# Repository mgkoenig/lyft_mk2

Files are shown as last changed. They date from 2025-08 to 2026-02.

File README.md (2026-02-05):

# LYFT mk2

This is an advanced next-level version of the famous [Lyft](https://github.com/mgkoenig/lyft) project. Apart from general improvements (lessons learned from the previous version) the focus of this re-design was placed on versatility and flexibility. Therefore, a dual-controller architecture was chosen. One controller is responsible for the desk communication only, while the second controller (__ESP32__) acts as interface platform with its enormous possibilities. Lyft can now be extended to support various access options, such as _web interfaces_ or _mobile apps_. Maybe your desk is one of the few things missing in your _home assistant_ setup? With the built-in ESP controller (running MicroPython), these and many more options are right at your fingertips.

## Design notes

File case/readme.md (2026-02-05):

Since the new design consists of two different PCBs, two different enclosures are also required: one for the ECU and the second for the HMI. All enclosure parts were created by [Extrutim](https://www.printables.com/@Extrutim), whose excellent work and attention to detail significantly contributed to the result.

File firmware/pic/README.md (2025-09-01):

The PIC controller and its firmware act as bridge module between the ESP32 and the desk. On the one hand, the controller takes care of the desk communication (including timings, move commands, error handling, etc). 
On the other hand, it provides an API which allows the ESP32 easily to access all supported features and read important information from the desk. 

## How to comunicate with the PIC controller
The controller is addressed using the UART interface with these settings: **115200@8N1**. 

## Sending a request to the controller
In order to trigger an event you need to send a certain request. Therefore, a simple communication protocol is used in order to make things easier. The structure of each request to the controller is as follows: 

[STX] [CMD] [LEN] [opt. DATA] [CHECKSUM] 

Where: 
| Element  | Description |
|---|---|
| STX | a start of transmission byte (0x4C) |
| CMD | the requested command (see API table) |
| LEN | length of optional data |
| DATA | if data is sent, it will be here |
| CHECKSUM | each request ends with a checksum byte |

## Receiving a response from the controller 
Every single request follows a response from the controller. In some cases, this response is just a simple ACK to the previous request. In other cases this response contains the requested data (e.g. current desk position, firmware version, etc). The structure of the response is as follows: 

[STX] [ECHO_CMD] [LEN] [ACK] [opt. DATA] [CHECKSUM]

As you can see, the frame has a similar structure as the request, but the content is interpreted slightly different:

| Element  | Description |
|---|---|
| STX | a start of transmission byte (0x4C) |
| ECHO_CMD | this is the same value as the received command, but it's or-ed with 0x80. For example, you requested a command code 0x12, then the echo_command will be 0x92. |
| LEN | length of optional data, but at least 0x01 due to the ACK byte |
| ACK | if there was no error, this ACK byte has the value 0x00. In case of an error, you can read an error value here (e.g. invalid command or invalid checksum). |
| DATA | the requested data (if no error occurred) |
| CHECKSUM | each response ends with a checksum byte |

..to be continued..

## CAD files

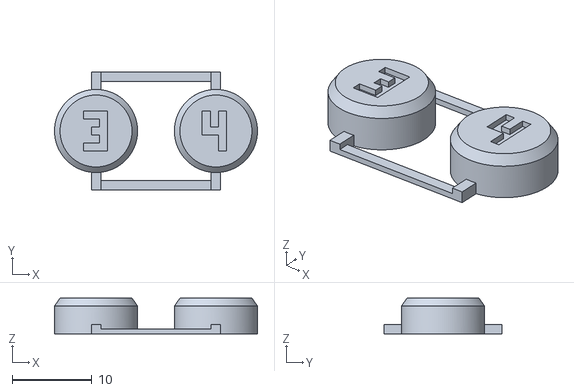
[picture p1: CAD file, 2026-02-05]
case/HMI_Button_2-3.stl
25.4 x 14.7 x 4.50

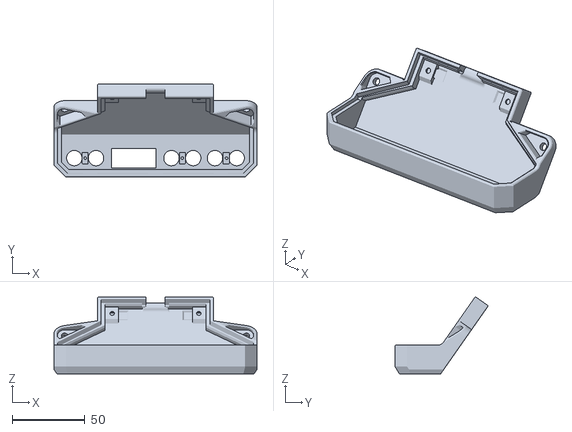
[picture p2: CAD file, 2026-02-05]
case/HMI_Case.stl
140.0 x 64.1 x 53.0

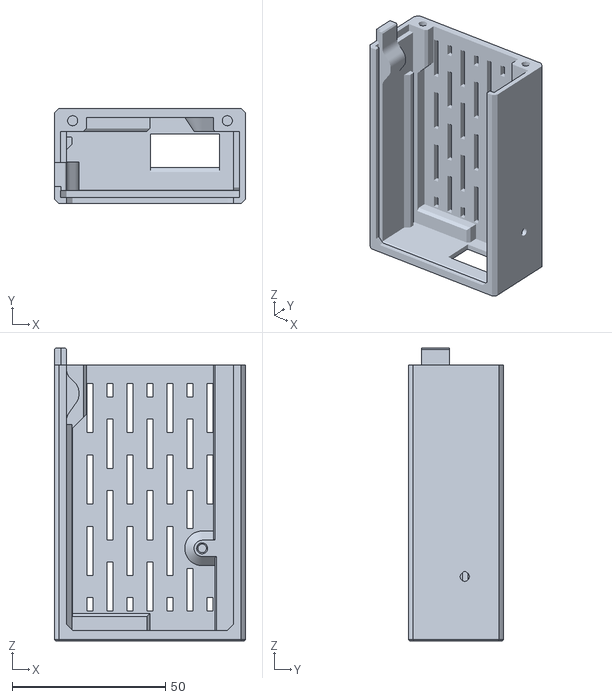
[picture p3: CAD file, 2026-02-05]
case/ECU_Case.stl
62.4 x 31.0 x 95.5

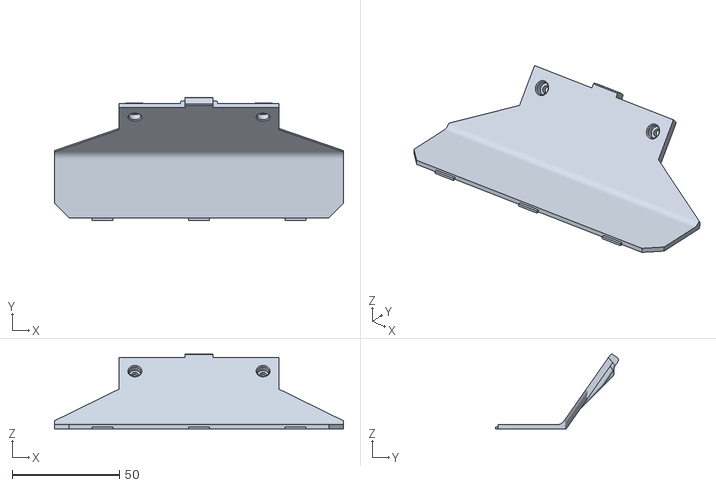
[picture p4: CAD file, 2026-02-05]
case/HMI_Lid.stl
134.8 x 57.3 x 35.0

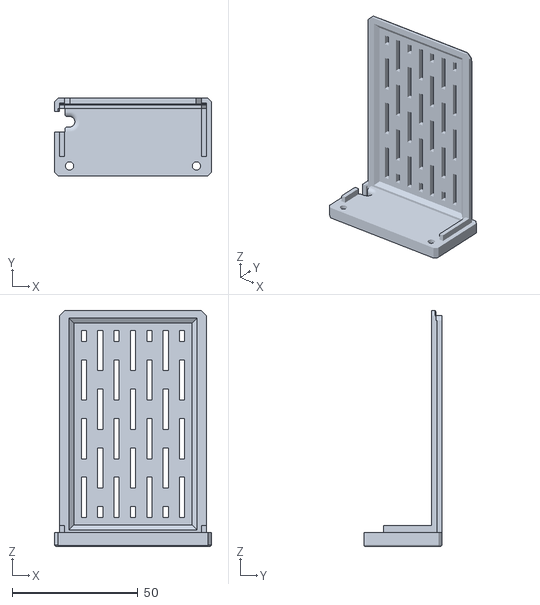
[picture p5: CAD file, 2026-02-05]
case/ECU_Lid.stl
62.4 x 31.0 x 93.7

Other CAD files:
case/HMI_Button_U-D.stl
case/HMI_Button_1-2.stl

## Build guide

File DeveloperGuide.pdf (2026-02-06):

# LYFT mk2

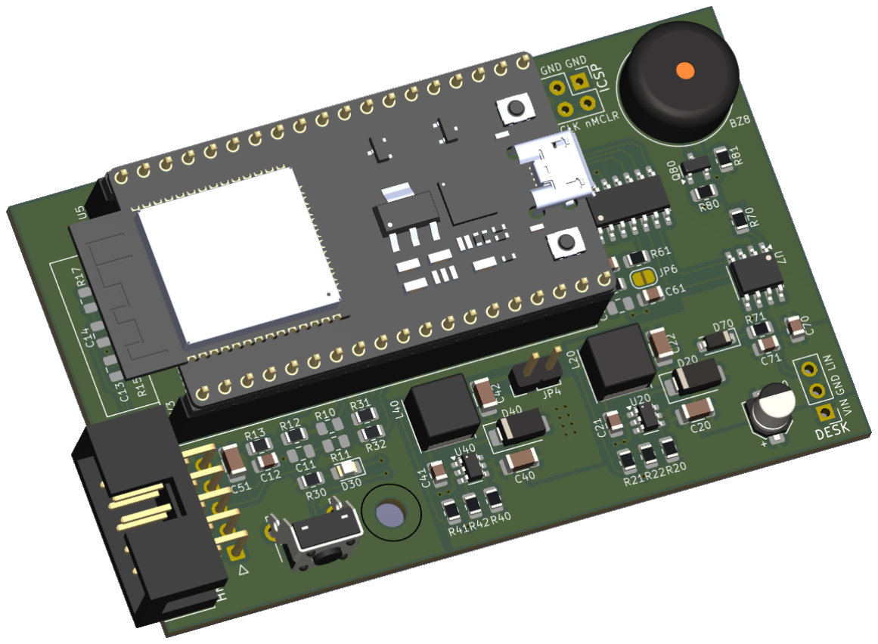
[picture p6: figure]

## Developer Guide

Welcome to LYFT mk2 !
This is an open-source DIY project designed to bring enhanced functionality and greater convenience to the famous IKEA BEKANT standing desk. The second generation of the LYFT remote control is built with both users and developers in mind: whether you want to adapt it for your own needs or contribute new features, the project is ready for you.
The redesigned dual-controller architecture allows you to control the desk using a simple Python API and run your own applications directly on the ESP platform — no detailed knowledge of the desk protocol is required, as the API and controller handle all tasks internally, enabling endless customization and innovation.
To facilitate a smooth start, the most important information has been summarized here for quick and efficient reference. All source files (hardware and software) are available on the GitHub repository, which can be accessed by scanning the QR code.

Getting Started

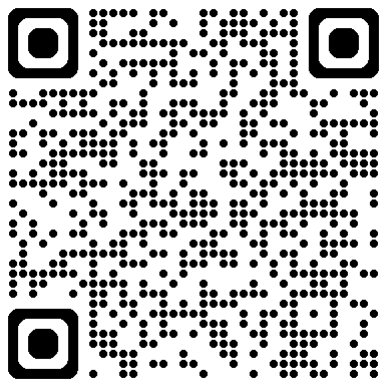
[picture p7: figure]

To upload your own software to the ESP module, connect it using a USB cable.

Warning: Before connecting the USB cable, Jumper four (JP4) must be removed. Failure to do so will damage the board!

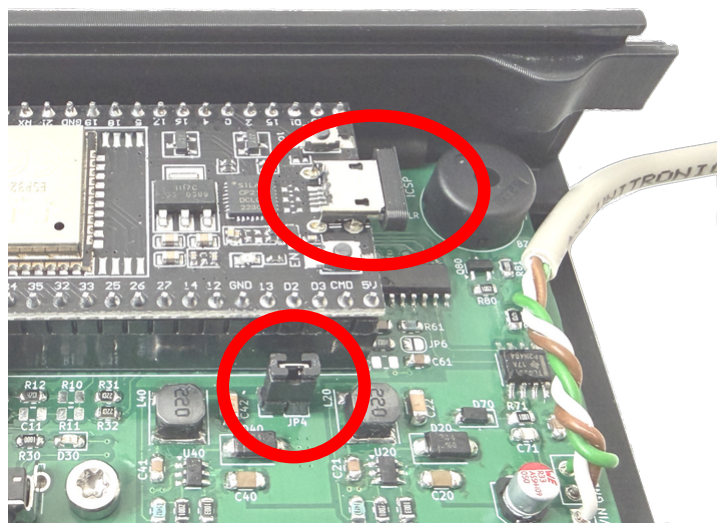
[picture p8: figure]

Jumper closed,
no USB cable connected

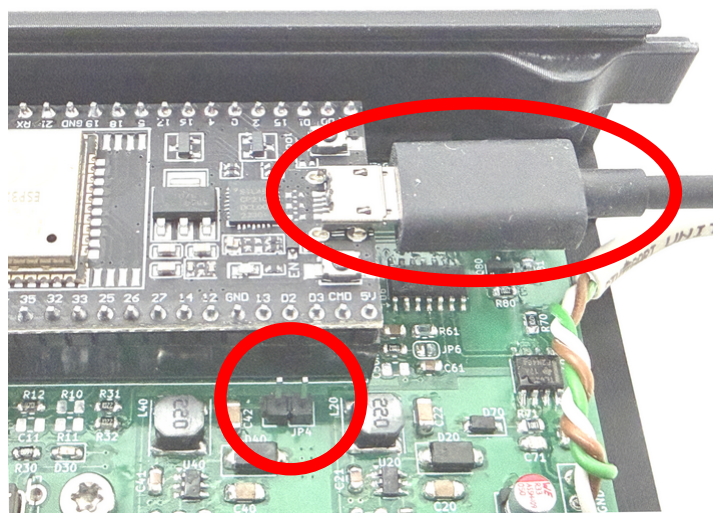
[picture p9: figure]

Jumper opened,
USB cable connected

Once the USB cable is connected to the host controller (ESP module), a connection to the PC must be established within 3 seconds. After that, no further input via the USB port will be recognized.

To communicate with the desk controller, the Bekant library must first be imported into the project. The library is already installed on the ESP module and can also be downloaded from the GitHub repository. After that, a desk object must be instantiated.

import bekant

desk = bekant.Bekant()

The desk communication must be explicitly initiated by the host controller (ESP
module) using the | startup() | command. The startup routine establishes
communication with the desk and sets the motors into operating mode. After a brief startup phase (approximately one second), the desk is ready for use. Communication can also be disabled using the shutdown() command.

desk.startup()

To move the desk, it is recommended to determine the highest and lowest motor positions first. The following queries can be used for this purpose. Every target position must lie within these two limits.

desk_upper_limit = desk.get_upper_limit() desk_lower_limit = desk.get_lower_limit()

The current desk position can be read using the | get_position() | command. The
returned value is of type int. The read position must be between upper_limit and
lower_limit.

desk_position = desk.get_position()

In order to move the desk to a desired position, the simple set_position() command can be used. The desk will automatically move to the specified position and stop once it is reached.

target_position = 2000
desk.set_position(target_position)

The desk can be stopped at any time using the stop() command.

desk.stop()

To avoid unexpected interruptions or error states, it is recommended to use the built-in watchdog of the desk controller. However, it should only be enabled after the startup routine, so that this routine can run without interruption. Once the watchdog is activated, a request must be sent to the desk controller every 100 ms. For example, the current desk position or the operating state can be queried. If no request is received, the desk controller will be reset by the watchdog. After a reset, the desk controller must be reactivated using the startup() function.

If necessary, the watchdog can be temporarily disabled using the
watchdog_disable() function.

desk.watchdog_enable()

To determine the current state of the desk, the get_state() function can be used. It returns a unique, current operating mode (e.g. idle, moving, limit reached, ...). The exact values and their corresponding states can be found in the Bekant library (class
State).

desk.get_state()

The Bekant library provides many additional functions. Further details can be found directly in the bekant.py library file or the GitHub repository. Finally, it should be noted that the existing implementation and usage of the library can serve as a good reference for how to use it effectively.

I wish you much enjoyment and success in extending and adapting the capabilities of your desk!

Happy coding!

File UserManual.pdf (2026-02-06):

# LYFT mk2

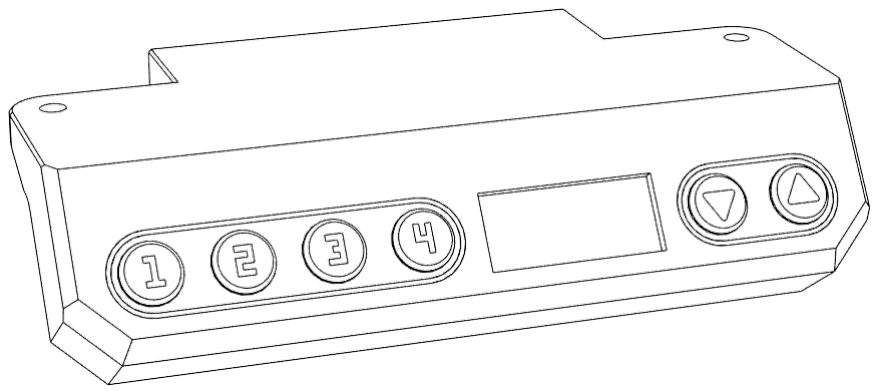
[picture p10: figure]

## User Manual

### I M P O R TA N T I N F O R M AT I O N

LYFT mk2 is a sophisticated remote control for electric height adjustable desks, compatible with the famous IKEA BEKANT desk. Designed as a plug & play solution, you can easily replace your originally provided remote control. LYFT mk2 comes completely assembled and is ready to use out of the box.

This project is an open-source DIY project and comes therefore without any liability or warranty. Usage of LYFT mk2 is always at your own risk. The originator is not liable of any damage the remote might cause. All source files are published on GitHub (github.com/mgkoenig/lyft_mk2) and licenced under the MIT license. Feel free to take a closer look at the design or to improve LYFT mk2 with even more useful features customised to your needs.

All product and company names are trademarks™ or registered® trademarks of their respective holders. Use of them does not imply any affiliation with or endorsement by them. IKEA is a registered trademark of Inter IKEA Systems BV.

Disclaimer of liability: In no event shall the originator be liable for any direct, indirect, punitive, incidental, special, consequential damages, to property or life, whatsoever arising out of or connected with the use or misuse of this product.

Exclusions from warranties: By purchasing this product you expressly agree that use of this product is at your sole risk. The originator does not and cannot warrant that the product will operate without errors.

All information and products described in this manual are provided on an “AS IS” basis. The originator does not make any representations or warranties of any kind, express or implied as to the operation of this product or the information made available to you, including implied warranties of merchantability and fitness for a particular purpose.

Furthermore, the originator's warranties for this product exclude any claims by the customer based on defects in the product caused by the customer, or by third parties beyond the originator's control.

2 | Document version 2.0 (12/2025)

### F U N C T I O N A L L AY O U T

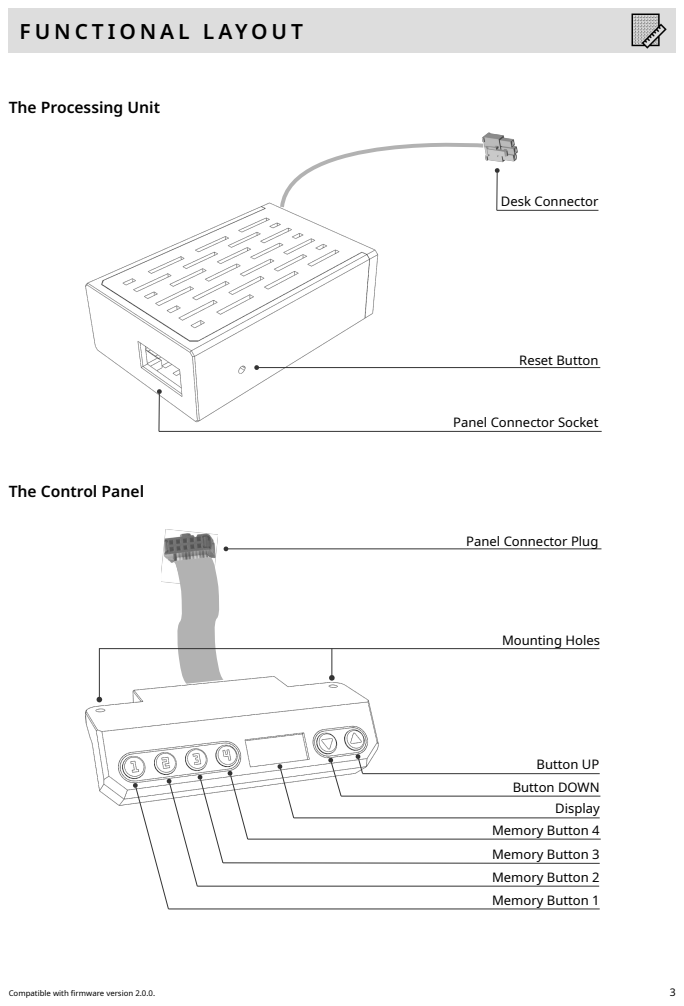
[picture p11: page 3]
Compatible with firmware version 2.0.0.; Desk Connector; Button UP Button DOWN Display Memory Button 4 Memory Button 3 Memory Button 2 Memory Button 1; Mounting Holes; Reset Button

The Processing Unit

Panel Connector Socket

The Control Panel

Panel Connector Plug

### I N S TA L L AT I O N

In order to use LYFT mk2, choose your preferred handling side and mount the control panel on the bottom edge of the desk. Use the destined mounting holes on the housing. Since no screws are provided with the shipment, you might use the original screws which were delivered together with the desk or use any two conventional [3 x 16mm] or [4 x 5/8”] wood screws instead. The processing unit can be stored in the mesh tray under the tabletop.

It’s absolutely necessary to connect all devices in the correct order. First, the control panel must be connected with the processing unit. After that, the processing unit can be connected to the desk.

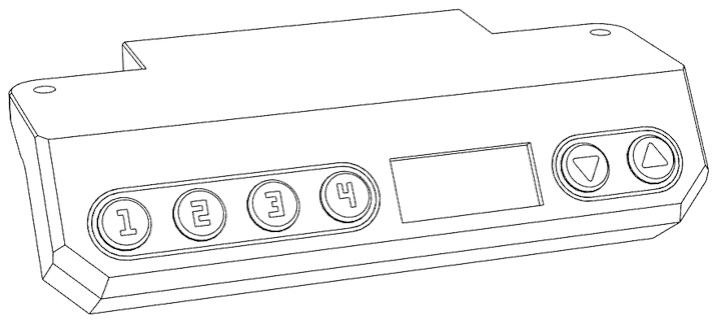
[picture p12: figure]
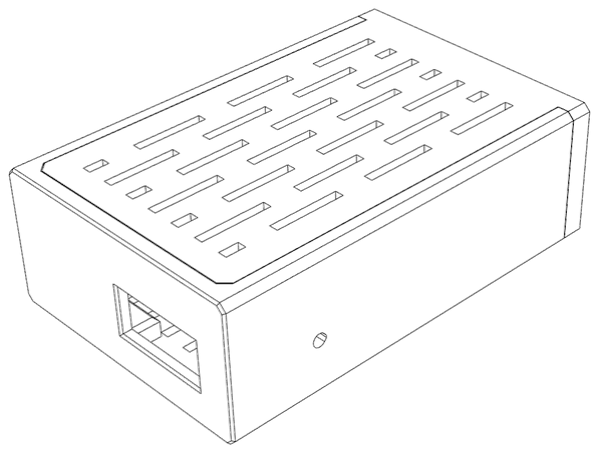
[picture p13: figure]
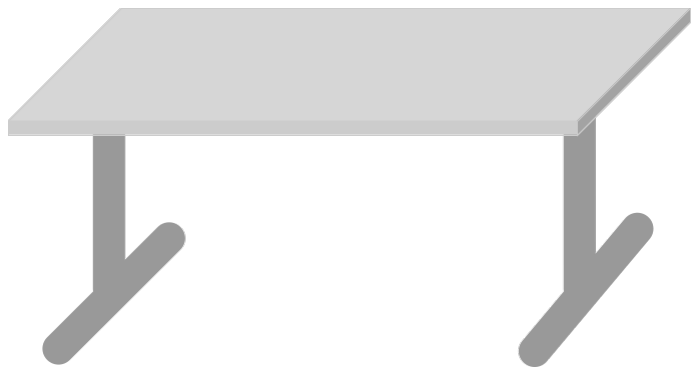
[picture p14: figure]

It takes about 5 seconds for the remote control to be ready for use after being plugged in.

1

2

### B A S I C F E AT U R E S

M O V I N G U P
To move your desk upwards, just press and hold the UP button on your LYFT remote control. The motors will automatically stop as soon as you release the button or the upper limit of the height is reached.

M O V I N G D O W N
To move your desk downwards, just press and hold the DOWN button on your LYFT remote control. The motors will automatically stop as soon as you release the button or the lower limit of the height is reached.

M O V I N G T O A S A V E D P O S I T I O N
If you have previously saved a comfortable desk position to one of the memory buttons (see the description in the upcoming settings chapter), you can move the desk to this height by pressing the corresponding button.
Compatible with firmware version 2.0.0. | 5

### S E T T I N G S M E N U

E N T E R T H E S E T T I N G S M E N U
In order to make any changes of the settings or to save a current desk position, you need to enter the settings menu. The menu is accessed by pressing the UP and DOWN buttons simultaneously for at least 2 seconds.

N A V I G A T E T H E S E T T I N G S M E N U
You can walk through the settings menu by using the UP and DOWN buttons to scroll to the next or previous page respectively.

L E A V E T H E S E T T I N G S M E N U
To exit the settings menu nothing special has to be done. Six seconds after the last button was pressed, the menu will save all its current settings and return to its default screen, showing the desk height.

S A V E A P O S I T I O N [ P ]
To save the current desk position, just enter the settings menu. The first entry of the menu shows a [P] which stands for position. By pushing one of the four memory buttons you will save the current height to the selected button.

2 sec.

D I S P L A Y B R I G H T N E S S [ L ]
You can change the brightness of the display to four different levels. Navigate within the settings menu to page [L]. Then, select the intensity by pushing one of the four memory buttons. Each button sets the brightness to a pre-defined value.

A U D I O C O N T R O L [ A ]
LYFT mk2 is equipped with a built-in audio transducer to generate audio signals and alarms. Navigate to menu page [A] to enable or disable these alarms.

D I S P L A Y - O N T I M E [ F ]
After pushing a button or adjusting the desk height to your preferred position, the display will stay on for a couple of seconds. You can change the display-on time on menu page [F]. Choose between 5, 10, 15, or 20 seconds display-on time using the memory buttons.

M E A S U R E M E N T U N I T [ U ]
By default the height of the desk is shown in centimetres. However, you can change the displayed unit to inch. Go to the unit page [U] within the menu and select your preferred measurement unit using memory button 1 or 2.
Compatible with firmware version 2.0.0. | 7

L E V E L C O R R E C T I O N [ C ]
The shown desk height might not be accurate due to level adjustment screws or a thicker tabletop. Therefore, you have the opportunity to tune the displayed position. Go to the level correction page [C] and set an offset value to the current height. The offset range is between plus/minus 9 centimetres. The offset value is always set as centimetre value – no matter which measurement unit you have selected. Use memory buttons 1 or 2 to increase or decrease the value.

### T R O U B L E S H O O T I N G

In rare cases, it might happen that the motors don’t respond to entries of the LYFT mk2 remote. In such a case, please disconnect your IKEA BEKANT desk from the power outlet for five minutes (it takes that long to discharge all remaining power) and try again. You can still double-check the flawless operation of your desk using the original remote control.

### A C K N O W L E D G M E N T S

All icons by icons8.com.

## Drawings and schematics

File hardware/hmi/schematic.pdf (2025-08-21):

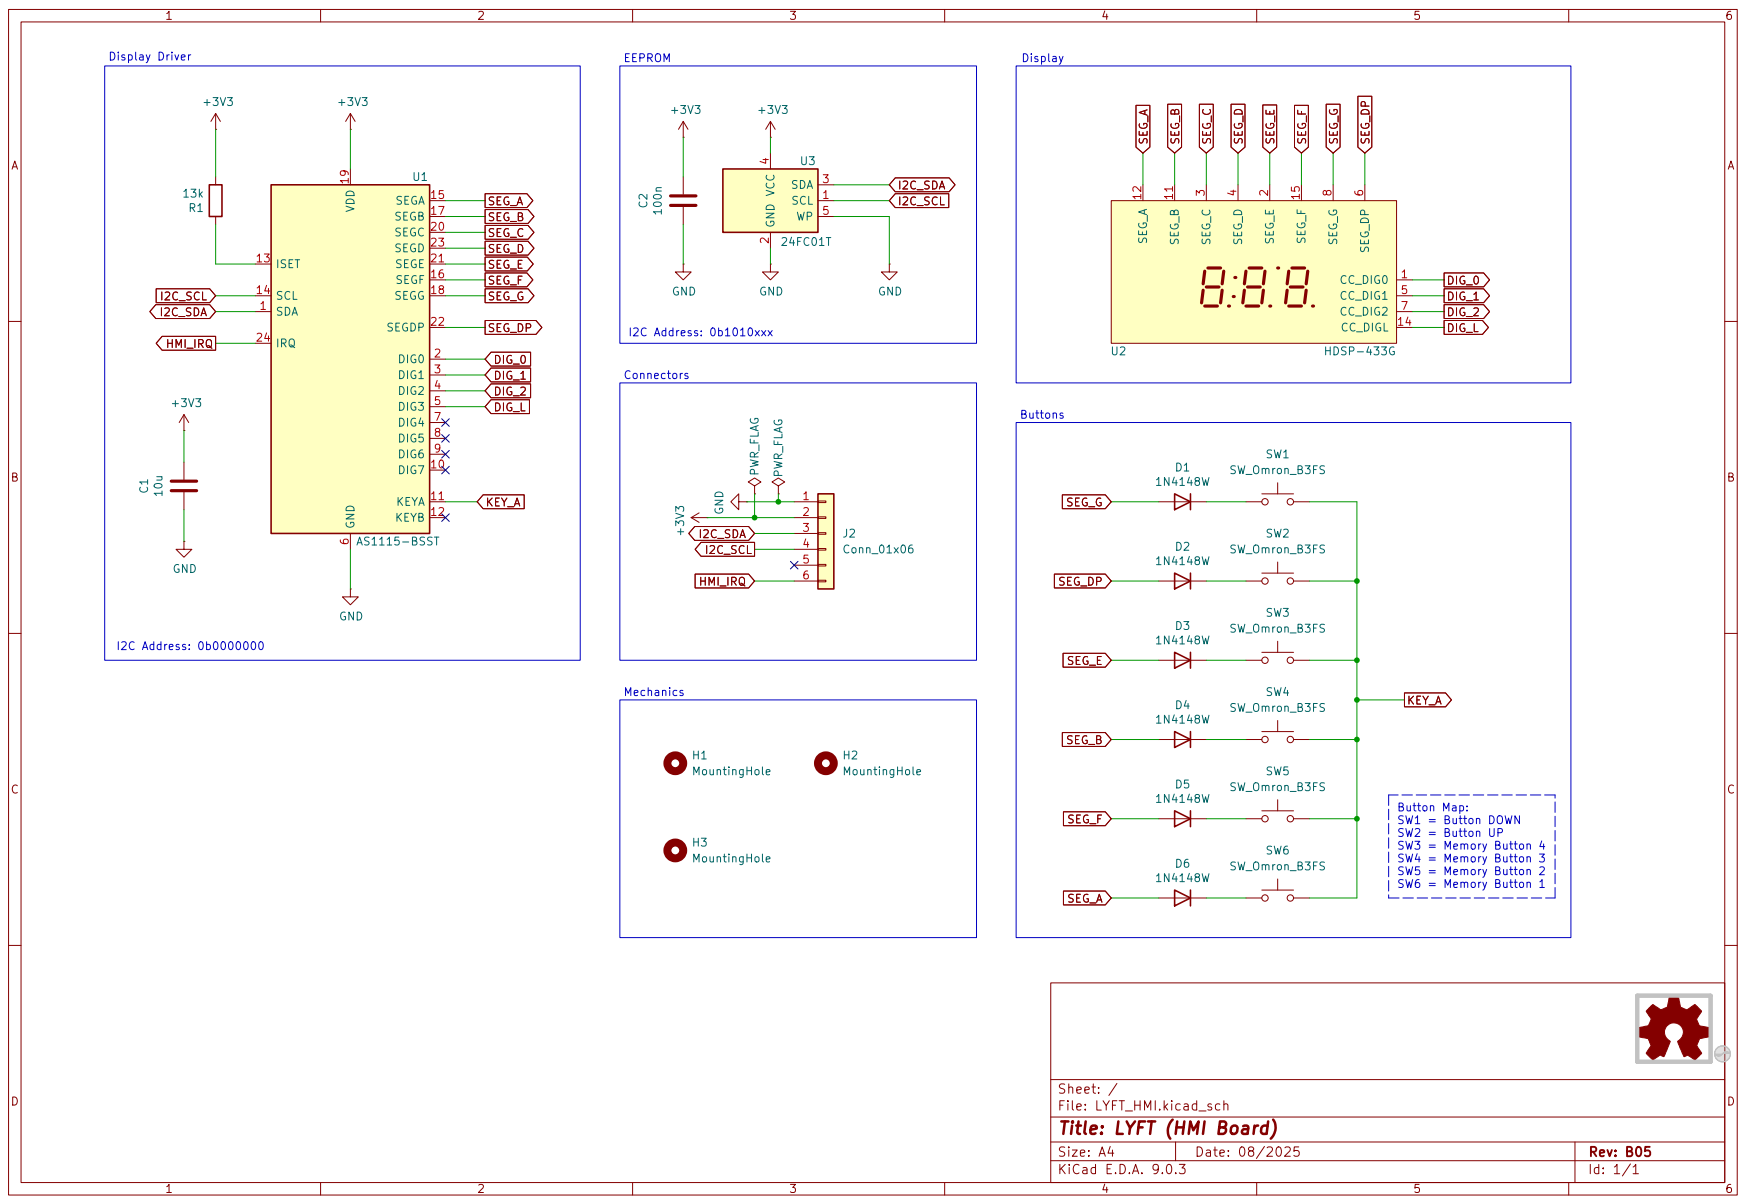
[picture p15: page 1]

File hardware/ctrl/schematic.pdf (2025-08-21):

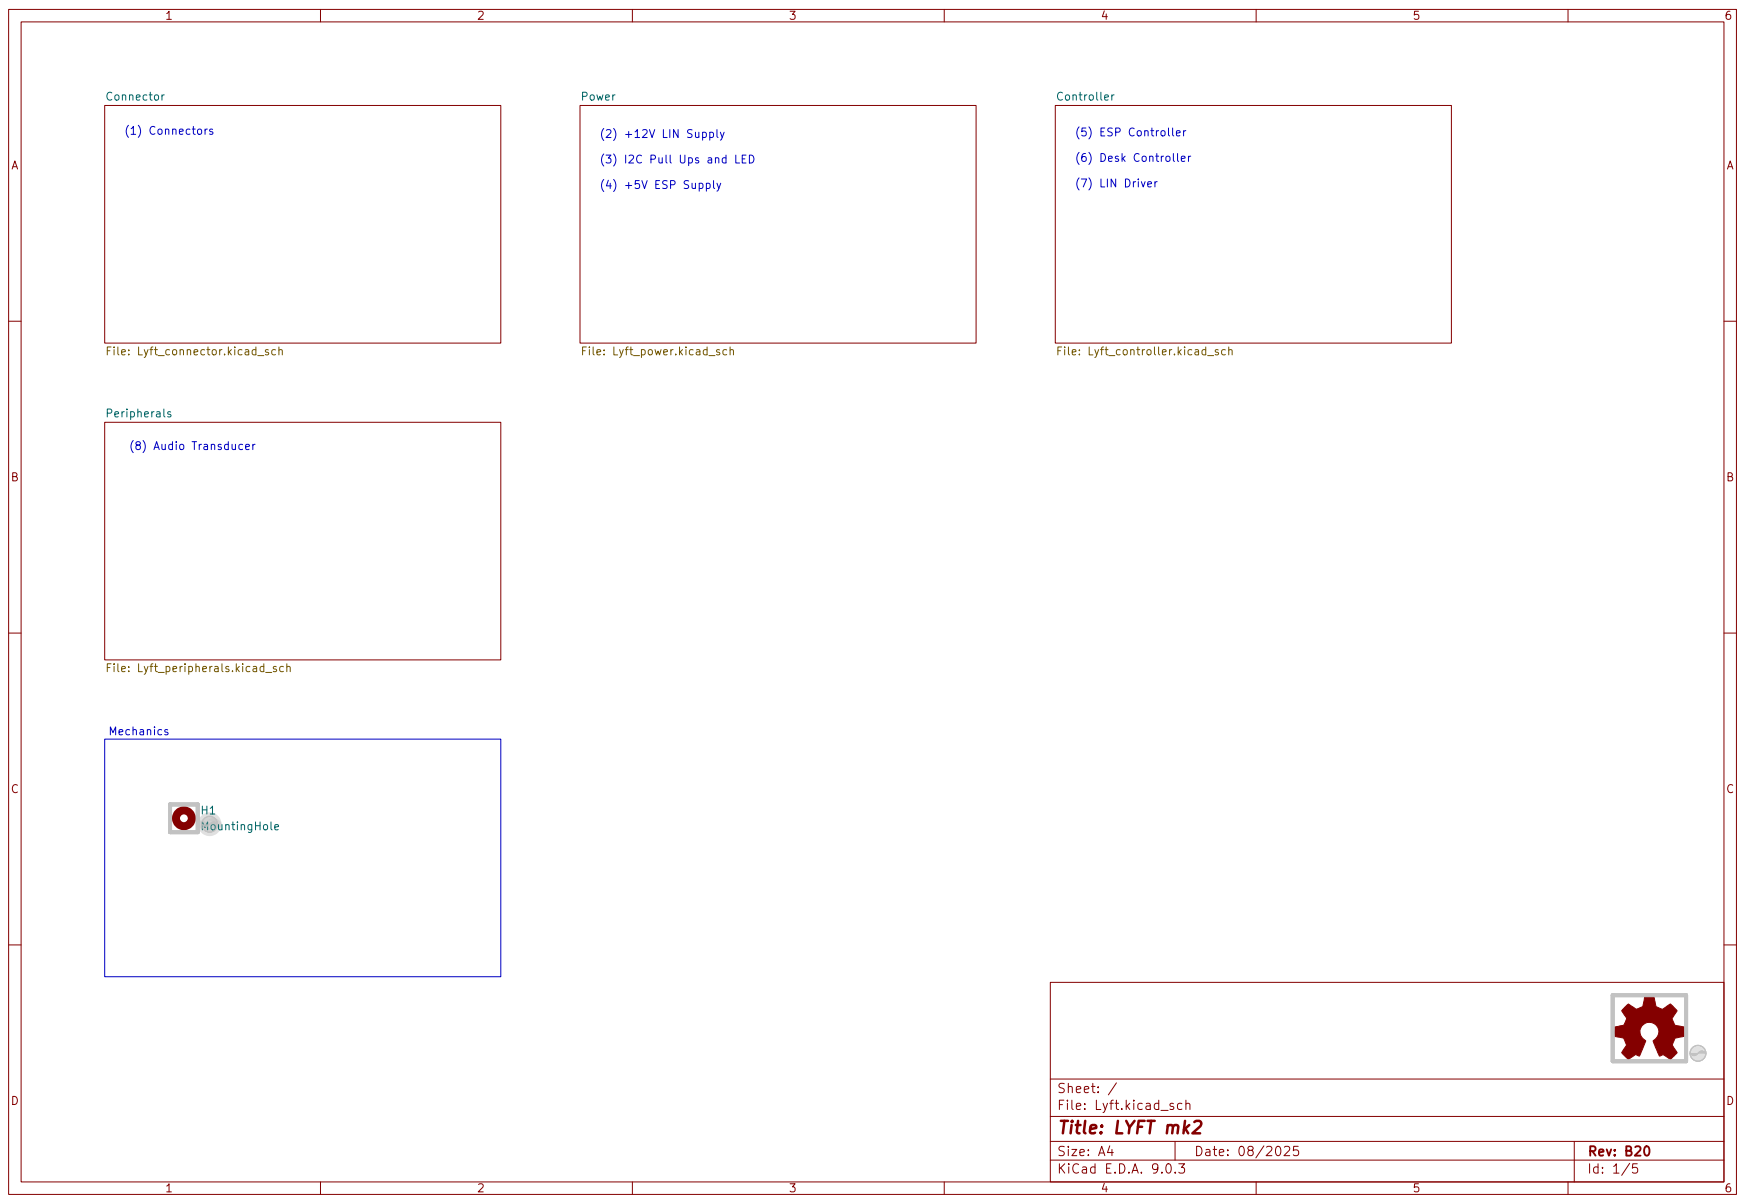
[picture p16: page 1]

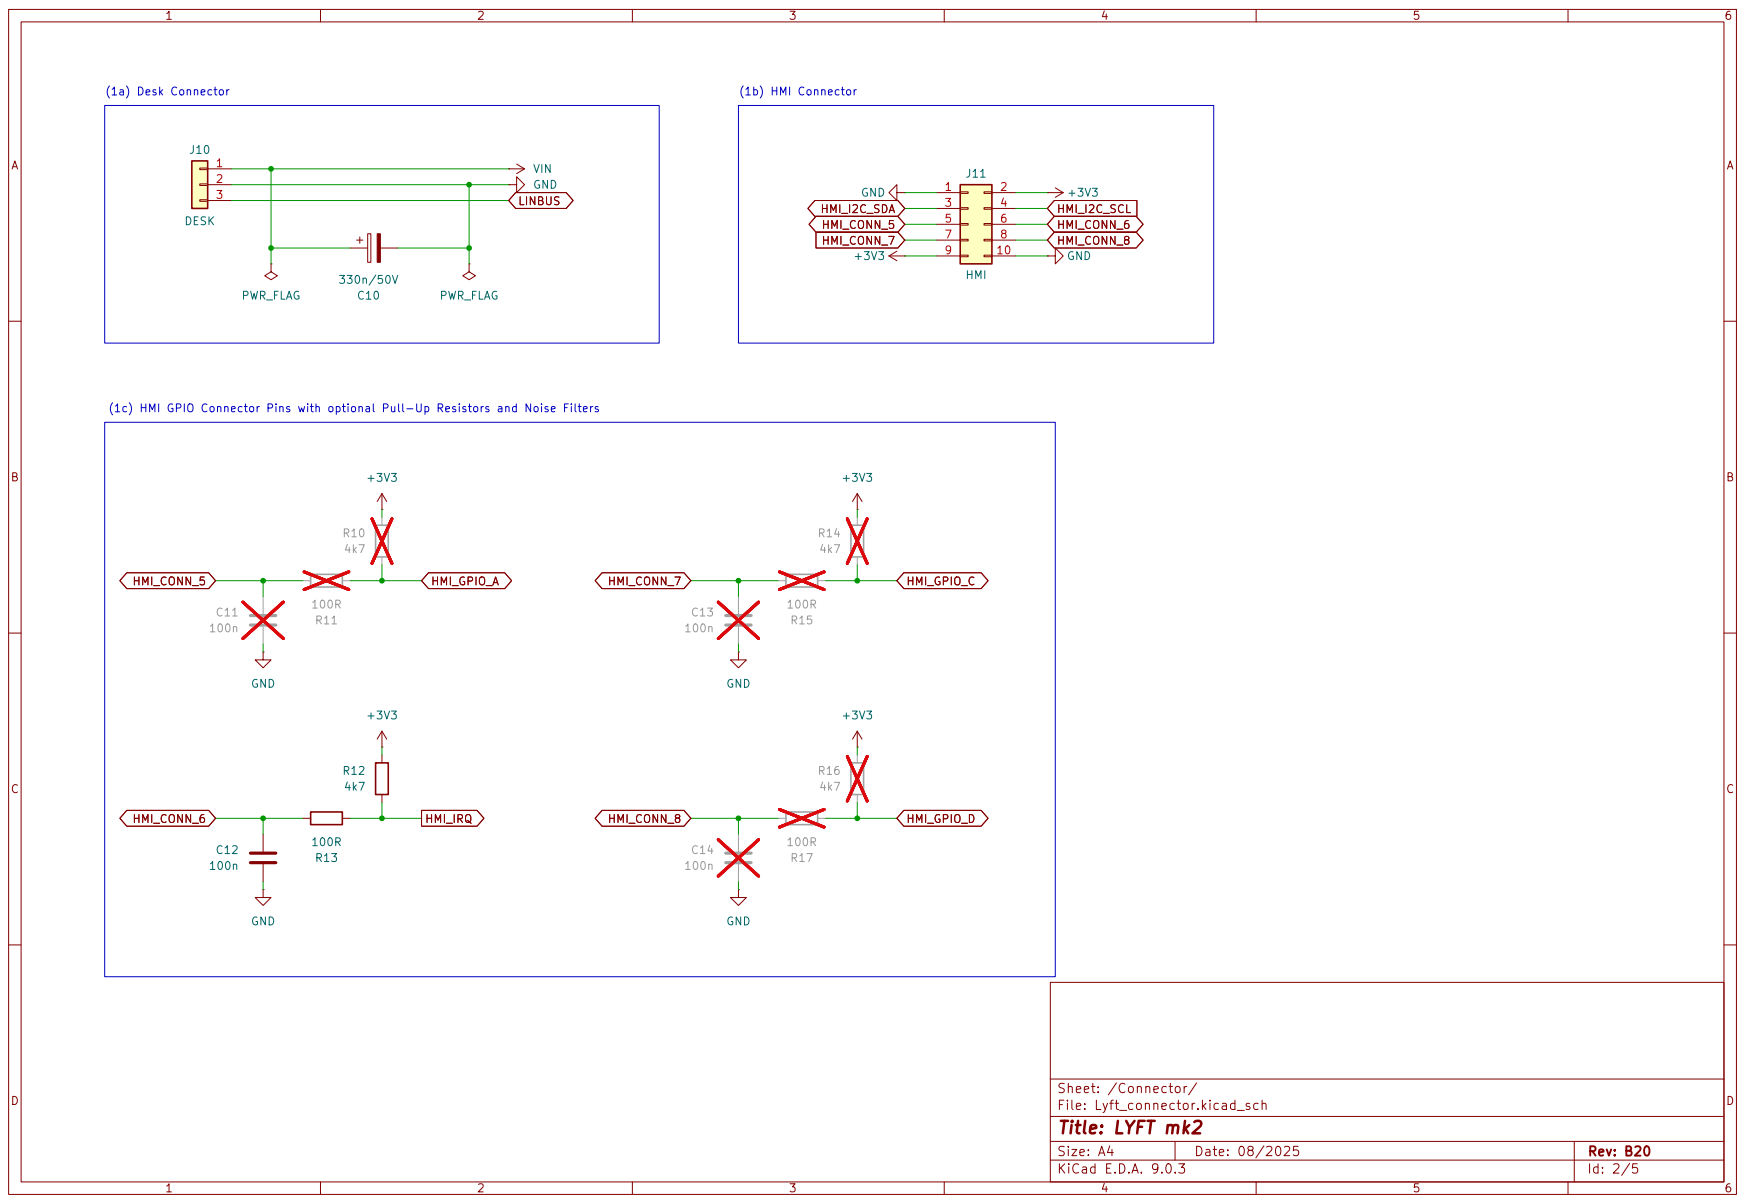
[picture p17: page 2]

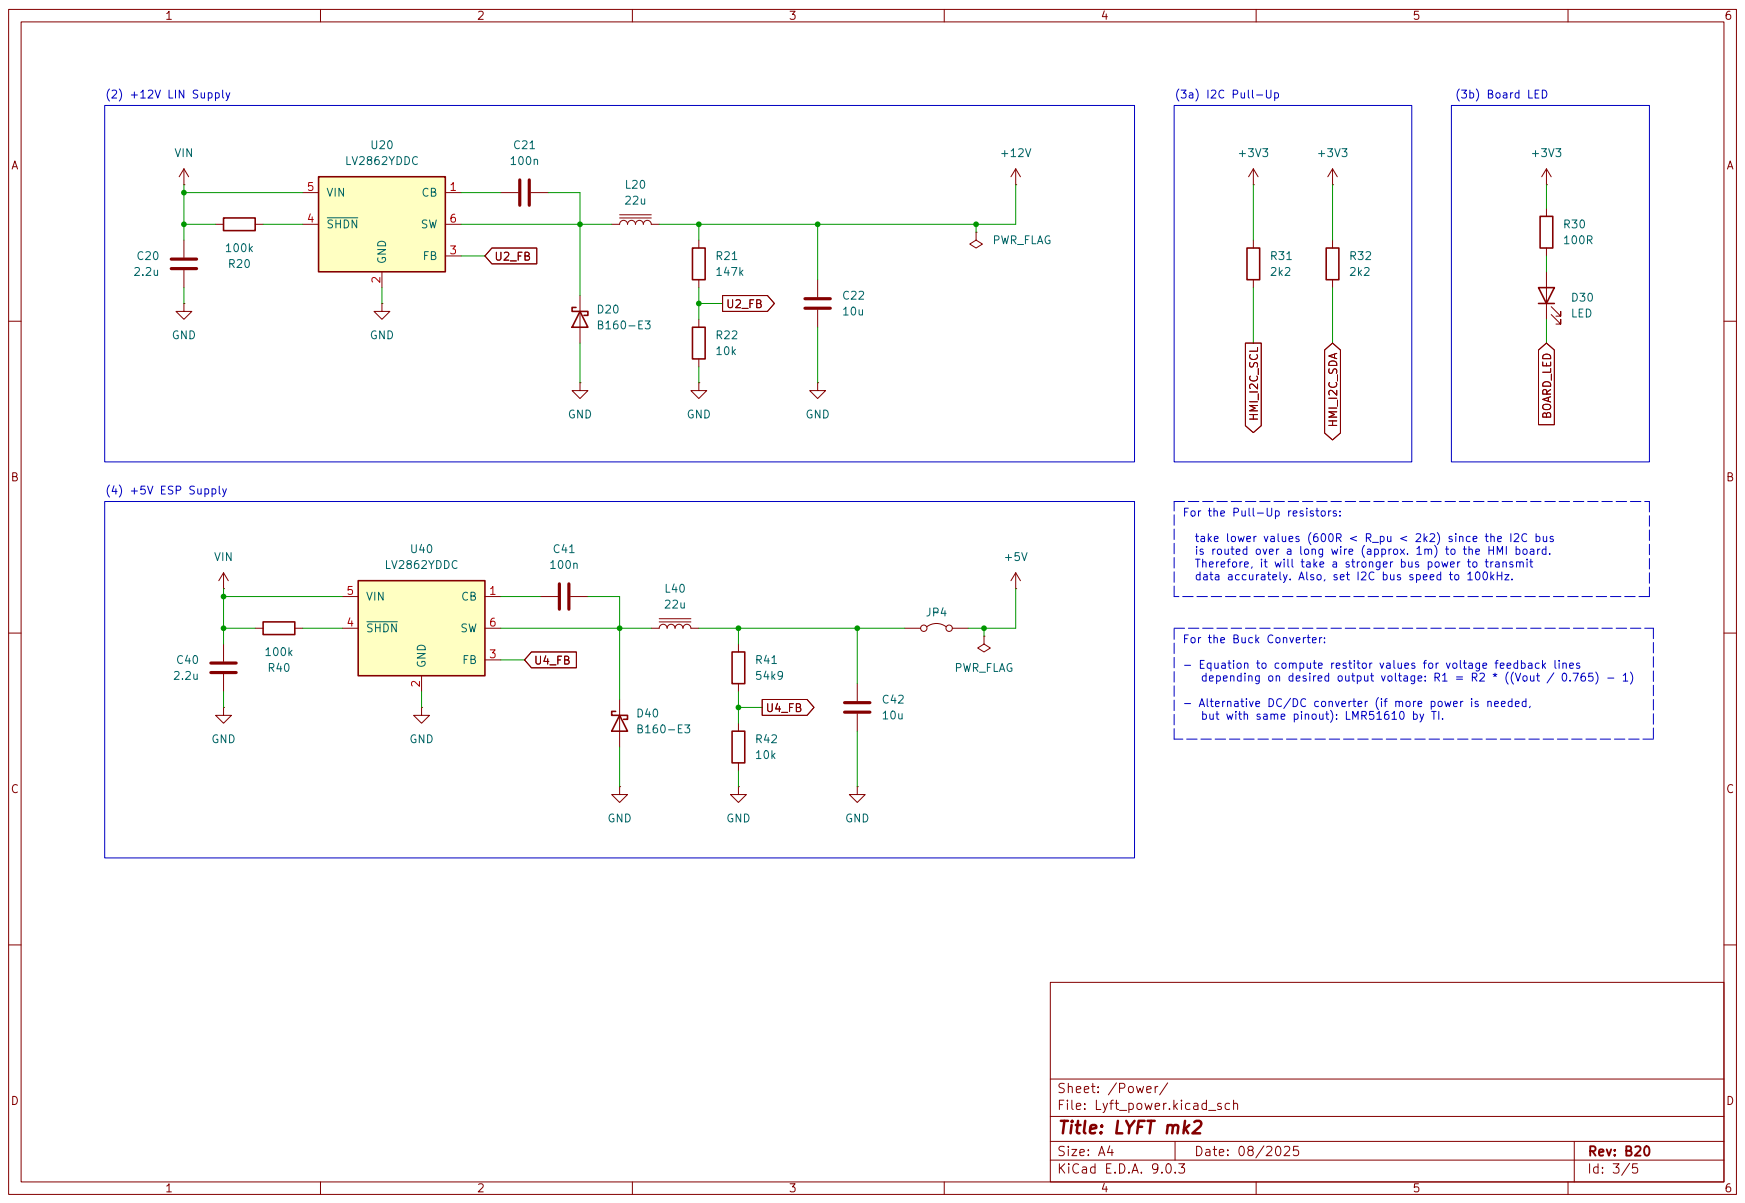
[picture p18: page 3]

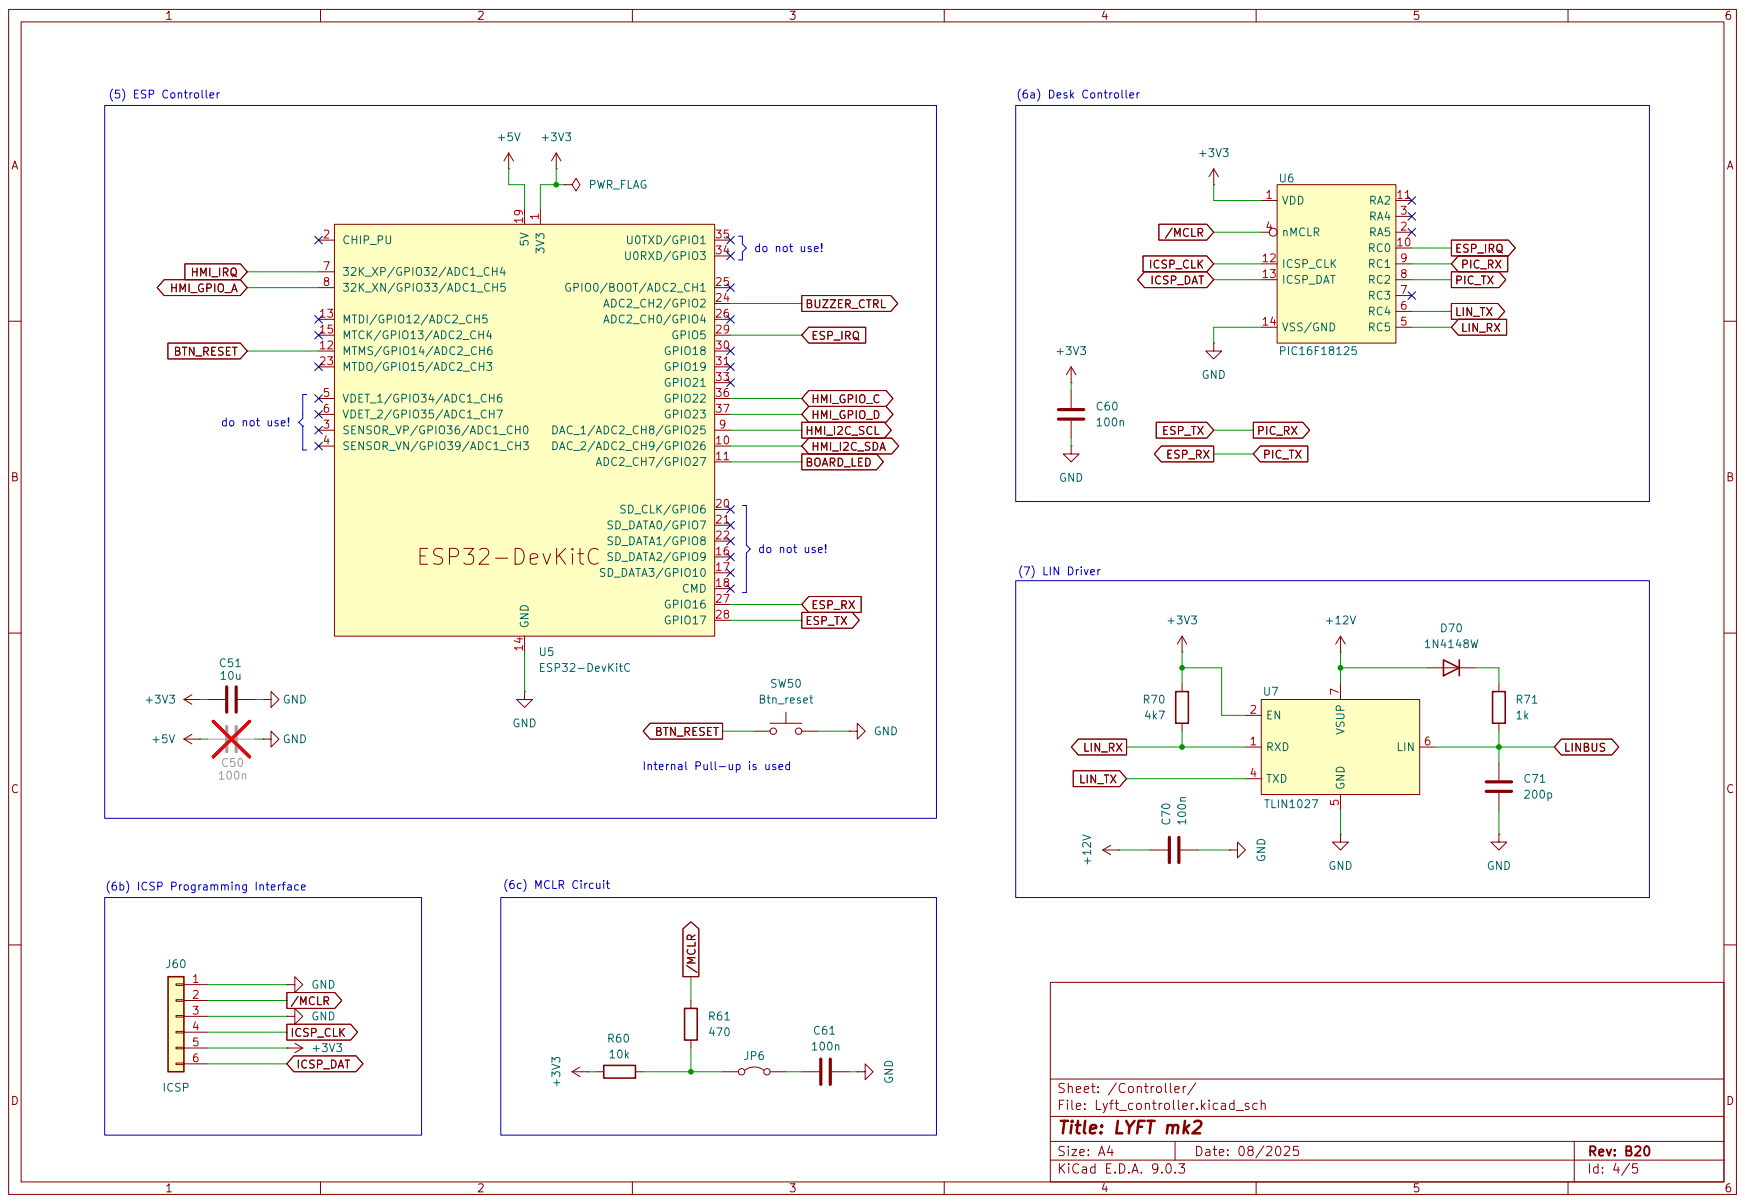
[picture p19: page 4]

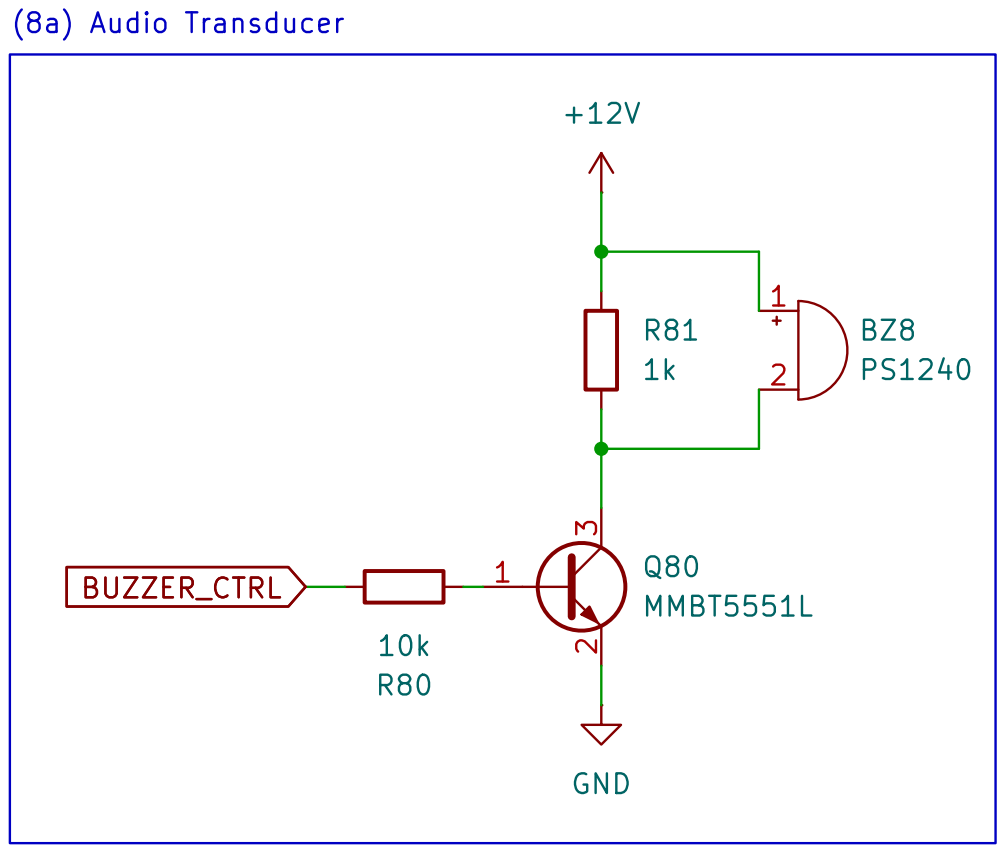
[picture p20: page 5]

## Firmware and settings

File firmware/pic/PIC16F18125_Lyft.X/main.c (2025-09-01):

 /*
 * MAIN Generated Driver File
 * 
 * @file main.c
 * 
 * @defgroup main MAIN
 * 
 * @brief This is the generated driver implementation file for the MAIN driver.
 *
 * @version MAIN Driver Version 1.0.2
 *
 * @version Package Version: 3.1.2
*/

/*
© [2025] Microchip Technology Inc. and its subsidiaries.

    Subject to your compliance with these terms, you may use Microchip 
    software and any derivatives exclusively with Microchip products. 
    You are responsible for complying with 3rd party license terms  
    applicable to your use of 3rd party software (including open source  
    software) that may accompany Microchip software. SOFTWARE IS ?AS IS.? 
    NO WARRANTIES, WHETHER EXPRESS, IMPLIED OR STATUTORY, APPLY TO THIS 
    SOFTWARE, INCLUDING ANY IMPLIED WARRANTIES OF NON-INFRINGEMENT,  
    MERCHANTABILITY, OR FITNESS FOR A PARTICULAR PURPOSE. IN NO EVENT 
    WILL MICROCHIP BE LIABLE FOR ANY INDIRECT, SPECIAL, PUNITIVE, 
    INCIDENTAL OR CONSEQUENTIAL LOSS, DAMAGE, COST OR EXPENSE OF ANY 
    KIND WHATSOEVER RELATED TO THE SOFTWARE, HOWEVER CAUSED, EVEN IF 
    MICROCHIP HAS BEEN ADVISED OF THE POSSIBILITY OR THE DAMAGES ARE 
    FORESEEABLE. TO THE FULLEST EXTENT ALLOWED BY LAW, MICROCHIP?S 
    TOTAL LIABILITY ON ALL CLAIMS RELATED TO THE SOFTWARE WILL NOT 
    EXCEED AMOUNT OF FEES, IF ANY, YOU PAID DIRECTLY TO MICROCHIP FOR 
    THIS SOFTWARE.
*/
#include "mcc_generated_files/system/system.h"
#include "config.h"
#include "bekant.h"
#include "host.h"

/*
    Main application
*/


static void respond_callDeskInit();
static void respond_callDeskDeinit();
static void respond_callDeskCalibration();

static void respond_getDeskState();
static void respond_getDeskDrift();
static void respond_getDeskPosition();
static void respond_getDeskUpperLimit();
static void respond_getDeskLowerLimit();

static void respond_setDeskHalt();
static void respond_setDeskPosition(uint16_t position);

static void respond_getMotorState(uint8_t unit);
static void respond_getMotorNodeId(uint8_t unit);
static void respond_getMotorScanId(uint8_t unit);
static void respond_getMotorProperty(uint8_t unit);
static void respond_getMotorPosition(uint8_t unit);
static void respond_getMotorUpperLimit(uint8_t unit);
static void respond_getMotorLowerLimit(uint8_t unit);

static void respond_getBoardRevision();
static void respond_getFirmwareVersion();
static void respond_getProtocolVersion();

static void respond_callWatchdogEnable();
static void respond_callWatchdogDisable();

static void respond_invalidCommand(uint8_t command);
static void respond_invalidChecksum(uint8_t command);
static void respond_invalidData(uint8_t command);

void wdt_enable();
void wdt_disable();
void wdt_clear();

void cb_tmr0();


bool wdt_isEnabled;
bool event_trigger;


int main(void)
{
    uint16_t position;
    enum desk_state op_mode;
    struct host_data_packet host_request;
    
    SYSTEM_Initialize();
    TMR0_OverflowCallbackRegister(&cb_tmr0);    // timer set to 5ms
    
    wdt_isEnabled = false;
    event_trigger = false;
 
    desk_init(true);
    host_init();
    
    INTERRUPT_GlobalInterruptEnable(); 
    INTERRUPT_PeripheralInterruptEnable(); 
    
    //desk_startup();

    while(1)
    {
        if (event_trigger == true)
        {
            op_mode = desk_getOpMode();
            if ((op_mode & STARTUP) == STARTUP) {
                desk_startup();
            }
            else if ((op_mode & OPERATION) == OPERATION) {
                desk_operation();
            } else {
                // desk is idle - do nothing.
            }

            event_trigger = false;
        }
        
        if ((host_newDataAvailable() == true) && (desk_isBusy() == false))
        {
            if (wdt_isEnabled == true) {
                wdt_clear();
            }
            
            // only process host_requests after desk communication is done. 
            // this ensures un-interrupted desk communication as well as stable values of data. 
            host_read(&host_request);
            
            if (host_verifyChecksum(host_request) == true)
            {
                switch (host_request.command)
                {
                    case CALL_DESK_INIT: respond_callDeskInit(); break;
                    case CALL_DESK_DEINIT: respond_callDeskDeinit(); break;
                    case CALL_DESK_CALIBRATION: respond_callDeskCalibration(); break;
                    
                    case GET_DESK_STATE: respond_getDeskState(); break; 
                    case GET_DESK_DRIFT: respond_getDeskDrift(); break; 
                    case GET_DESK_POSITION: respond_getDeskPosition(); break;                    
                    case GET_DESK_UPPER_LIMIT: respond_getDeskUpperLimit(); break;
                    case GET_DESK_LOWER_LIMIT: respond_getDeskLowerLimit(); break;
                    
                    case SET_DESK_HALT: respond_setDeskHalt(); break;
                    case SET_DESK_POSITION: 
                        if (host_request.length == 2) {
                            position = ((host_request.data[0] << 8) | host_request.data[1]);
                            respond_setDeskPosition(position);
                        } else {
                            respond_invalidData(host_request.command);
                        }
                        break;
                    
                    case GET_MOTOR_LEFT_STATE: respond_getMotorState(UNIT_LEFT); break;
                    case GET_MOTOR_LEFT_POSITION: respond_getMotorPosition(UNIT_LEFT); break;
                    case GET_MOTOR_LEFT_UPPER_LIMIT: respond_getMotorUpperLimit(UNIT_LEFT); break;
                    case GET_MOTOR_LEFT_LOWER_LIMIT: respond_getMotorLowerLimit(UNIT_LEFT); break;
                    case GET_MOTOR_LEFT_PROPERTY: respond_getMotorProperty(UNIT_LEFT); break;
                    case GET_MOTOR_LEFT_NODE_ID: respond_getMotorNodeId(UNIT_LEFT); break;
                    case GET_MOTOR_LEFT_SCAN_ID: respond_getMotorScanId(UNIT_LEFT); break;
                        
                    case GET_MOTOR_RIGHT_STATE: respond_getMotorState(UNIT_RIGHT); break;
                    case GET_MOTOR_RIGHT_POSITION: respond_getMotorPosition(UNIT_RIGHT); break;
                    case GET_MOTOR_RIGHT_UPPER_LIMIT: respond_getMotorUpperLimit(UNIT_RIGHT); break;
                    case GET_MOTOR_RIGHT_LOWER_LIMIT: respond_getMotorLowerLimit(UNIT_RIGHT); break;
                    case GET_MOTOR_RIGHT_PROPERTY: respond_getMotorProperty(UNIT_RIGHT); break;
                    case GET_MOTOR_RIGHT_NODE_ID: respond_getMotorNodeId(UNIT_RIGHT); break;
                    case GET_MOTOR_RIGHT_SCAN_ID: respond_getMotorScanId(UNIT_RIGHT); break;
                    
                    case GET_BOARD_REVISION: respond_getBoardRevision(); break;
                    case GET_FIRMWARE_VERSION: respond_getFirmwareVersion(); break;
                    case GET_PROTOCOL_VERSION: respond_getProtocolVersion(); break;
                    
                    case CALL_WATCHDOG_ENABLE: respond_callWatchdogEnable(); break;
                    case CALL_WATCHDOG_DISABLE: respond_callWatchdogDisable(); break;

                    default: respond_invalidCommand(host_request.command); break;
                }
            }
            else 
            {
                respond_invalidChecksum(host_request.command);
            }
        }
    }    
}


void wdt_enable()
{
    volatile uint8_t t = WDTCON0;
    WDTCON0bits.WDTSEN = 0b1;
    wdt_isEnabled = true;
}

void wdt_disable()
{
    WDTCON0bits.WDTSEN = 0b0;
    wdt_isEnabled = false;
}

void wdt_clear()
{
    volatile uint8_t t = WDTCON0;   // arm the WDT before clearing it
    CLRWDT();
} 

void cb_tmr0()
{
    event_trigger = true;
}

static void respond_callDeskInit()
{
    uint8_t state;
    struct host_data_packet host_response;
    
    state = desk_getOpMode();
    host_response.command = (CALL_DESK_INIT | 0x80);
    host_response.length = 1;
    
    if (state == IDLE)
    {
        desk_startup();
        TMR0_Start();     // timer has to be enabled all time since it's used for the watchdog
        //wdt_enable();
        
        host_response.data[0] = E_OK;
    }
    else
    {
        host_response.data[0] = E_DESK_NOT_IDLE;        
    }

    host_calcChecksum(&host_response);
    host_write(host_response);
}

static void respond_callDeskDeinit()
{
    struct host_data_packet host_response;
    
    TMR0_Stop();      
    wdt_disable();
    desk_init(false);
    
    host_response.command = (CALL_DESK_DEINIT | 0x80);
    host_response.length = 1;
    host_response.data[0] = E_OK;
    host_calcChecksum(&host_response);

    host_write(host_response);
}

static void respond_callDeskCalibration()
{
    uint8_t state;
    struct host_data_packet host_response;
    
    state = desk_getOpMode();
    host_response.command = (CALL_DESK_CALIBRATION | 0x80);
    host_response.length = 1;
    
    if (state == OPERATION_NORMAL) 
    {
        desk_runCalibration();
        host_response.data[0] = E_OK;
    }
    else
    {
        host_response.data[0] = E_DESK_BUSY;
    }
        
    host_calcChecksum(&host_response);    
    host_write(host_response);
}

static void respond_getBoardRevision()
{    
    struct host_data_packet host_response;
    
    host_response.command = (GET_BOARD_REVISION | 0x80);
    host_response.length = 4;
    host_response.data[0] = E_OK;
    host_response.data[1] = (uint8_t) BOARD_REVISION[0];
    host_response.data[2] = (uint8_t) BOARD_REVISION[1];
    host_response.data[3] = (uint8_t) BOARD_REVISION[2];    
    host_calcChecksum(&host_response);
        
    host_write(host_response);
}

static void respond_getFirmwareVersion()
{
    struct host_data_packet host_response;
    
    host_response.command = (GET_FIRMWARE_VERSION | 0x80);
    host_response.length = 4;
    host_response.data[0] = E_OK;
    host_response.data[1] = FIRMWARE_VERSION_MAJOR; 
    host_response.data[2] = FIRMWARE_VERSION_MINOR;
    host_response.data[3] = FIRMWARE_VERSION_PATCH;
    host_calcChecksum(&host_response);

    host_write(host_response);
}

static void respond_getProtocolVersion()
{
    struct host_data_packet host_response;
    
    host_response.command = (GET_PROTOCOL_VERSION | 0x80);
    host_response.length = 2;
    host_response.data[0] = E_OK;
    host_response.data[1] = PROTOCOL_VERSION; 
    host_calcChecksum(&host_response);

    host_write(host_response);
}

static void respond_getDeskDrift()
{
    uint8_t drift;
    struct host_data_packet host_response;
    
    drift = desk_getDrift();
    
    host_response.command = (GET_DESK_DRIFT | 0x80);
    host_response.length = 2;
    host_response.data[0] = E_OK;
    host_response.data[1] = drift; 
    host_calcChecksum(&host_response);

    host_write(host_response);
}

static void respond_getDeskPosition()
{
    uint8_t state;
    uint16_t position;
    struct host_data_packet host_response;
    
    state = desk_getOpMode();    
    host_response.command = (GET_DESK_POSITION | 0x80);
    
    if ((state & OPERATION) == OPERATION)
    {
        position = desk_getPosition();
    
        host_response.length = 3;
        host_response.data[0] = E_OK;
        host_response.data[1] = ((position & 0xFF00) >> 8); 
        host_response.data[2] = (position & 0x00FF);
        
    }
    else
    {
        host_response.length = 1;
        host_response.data[0] = E_DESK_NOT_READY;
    }
    
    host_calcChecksum(&host_response);
    host_write(host_response);
}

static void respond_setDeskPosition(uint16_t position)
{
    uint8_t state;
    uint16_t diff;
    uint16_t current_position;
    uint16_t upper_limit, lower_limit;
    struct host_data_packet host_response;
    
    state = desk_getOpMode();
    upper_limit = desk_getUpperLimit();
    lower_limit = desk_getLowerLimit();
    current_position = desk_getPosition();
    host_response.command = (SET_DESK_POSITION | 0x80);
    host_response.length = 1;
    
    // some preliminary checks
    if (state == OPERATION_NORMAL)
    {
        if ((lower_limit <= position) && (position <= upper_limit))
        {            
            if (position > current_position) 
            { // we want to go up                
                if (upper_limit > (current_position + DESK_STOPPING_DISTANCE))
                {                    
                    diff = (position - current_position);
                
                    if (diff > DESK_STOPPING_DISTANCE) 
                    {
                        desk_setPosition(position);        
                        host_response.data[0] = E_OK;  
                    }
                    else
                    {
                        // error min distance
                        host_response.data[0] = E_DESK_MIN_DISTANCE;
                    }                 
                }
                else 
                {
                    // error upper limit reached
                    host_response.data[0] = E_DESK_UPPER_LIMIT_REACHED;
                }
            }
            
            else if (position < current_position)
            { // we want to go down 
                
                
                if (lower_limit < (current_position - DESK_STOPPING_DISTANCE))
                {                    
                    diff = (current_position - position);
                
                    if (diff > DESK_STOPPING_DISTANCE) 
                    {
                        desk_setPosition(position);        
                        host_response.data[0] = E_OK;  
                    }
                    else
                    {
                        // error min distance
                        host_response.data[0] = E_DESK_MIN_DISTANCE;
                    }                 
                }
                else 
                {
                    // error lower limit reached
                    host_response.data[0] = E_DESK_LOWER_LIMIT_REACHED;
                }
            }
        }
        else
        {
            host_response.data[0] = E_INVALID_DATA;
        }
    }
    else 
    {
        host_response.data[0] = E_DESK_BUSY;
    }
        
    host_calcChecksum(&host_response);         
    host_write(host_response);
}

static void respond_getDeskUpperLimit()
{
    uint16_t limit;
    struct host_data_packet host_response;
    
    limit = desk_getUpperLimit();
    
    host_response.command = (GET_DESK_UPPER_LIMIT | 0x80);
    host_response.length = 3;
    host_response.data[0] = E_OK;
    host_response.data[1] = ((limit & 0xFF00) >> 8); 
    host_response.data[2] = (limit & 0x00FF);
    
    host_calcChecksum(&host_response);
    host_write(host_response);
}

static void respond_getDeskLowerLimit()
{
    uint16_t limit;
    struct host_data_packet host_response;
    
    limit = desk_getLowerLimit();
    
    host_response.command = (GET_DESK_LOWER_LIMIT | 0x80);
    host_response.length = 3;
    host_response.data[0] = E_OK;
    host_response.data[1] = ((limit & 0xFF00) >> 8); 
    host_response.data[2] = (limit & 0x00FF);
    host_calcChecksum(&host_response);

    host_write(host_response);
}

static void respond_setDeskHalt()
{
    uint16_t position;
    struct host_data_packet host_response;
    
    position = desk_getPosition();
    desk_setPosition(position);
    
    host_response.command = (SET_DESK_HALT | 0x80);
    host_response.length = 1;
    host_response.data[0] = E_OK;
    
    host_calcChecksum(&host_response);
    host_write(host_response);
}

static void respond_getDeskState()
{
    uint8_t state;
    struct host_data_packet host_response;
    
    state = desk_getOpMode();
    
    host_response.command = (GET_DESK_STATE | 0x80);
    host_response.length = 2;
    host_response.data[0] = E_OK;
    host_response.data[1] = state; 
    
    host_calcChecksum(&host_response);
    host_write(host_response);
}

static void respond_getMotorProperty(uint8_t unit)
{
    uint8_t property = 0xFF;
    struct host_data_packet host_response;
    
    switch (unit)
    {
        case UNIT_LEFT:
            host_response.command = (GET_MOTOR_LEFT_PROPERTY | 0x80);
            property = motor_getProperty(UNIT_LEFT);
            break;
        case UNIT_RIGHT:
            host_response.command = (GET_MOTOR_RIGHT_PROPERTY | 0x80);
            property = motor_getProperty(UNIT_RIGHT);
            break;
        default: break;
    }
    
    host_response.length = 2;
    host_response.data[0] = E_OK;
    host_response.data[1] = property;
    
    host_calcChecksum(&host_response);
    host_write(host_response);
}

static void respond_getMotorState(uint8_t unit)
{
    uint8_t state;
    struct host_data_packet host_response;
    
    switch (unit)
    {
        case UNIT_LEFT: 
            host_response.command = (GET_MOTOR_LEFT_STATE | 0x80);
            state = motor_getState(UNIT_LEFT); 
            break;
        case UNIT_RIGHT:
            host_response.command = (GET_MOTOR_RIGHT_STATE | 0x80);
            state = motor_getState(UNIT_RIGHT); 
            break;
        default: break;
    }
    
    host_response.length = 2;
    host_response.data[0] = E_OK;
    host_response.data[1] = state;
    
    host_calcChecksum(&host_response);
    host_write(host_response);
}

static void respond_getMotorPosition(uint8_t unit)
{
    uint16_t position;
    struct host_data_packet host_response;
    
    switch (unit)
    {
        case UNIT_LEFT: 
            host_response.command = (GET_MOTOR_LEFT_POSITION | 0x80);
            position = motor_getPosition(UNIT_LEFT); 
            break;
        case UNIT_RIGHT:
            host_response.command = (GET_MOTOR_RIGHT_POSITION | 0x80);
            position = motor_getPosition(UNIT_RIGHT); 
            break;
        default: break;
    }
    
    host_response.length = 3;
    host_response.data[0] = E_OK;
    host_response.data[1] = ((position & 0xFF00) >> 8);
    host_response.data[2] = (position & 0xFF);
    
    host_calcChecksum(&host_response);
    host_write(host_response);
}

static void respond_getMotorUpperLimit(uint8_t unit)
{
    uint16_t limit;
    struct host_data_packet host_response;
    
    switch (unit)
    {
        case UNIT_LEFT: 
            host_response.command = (GET_MOTOR_LEFT_UPPER_LIMIT | 0x80);
            limit = motor_getUpperLimit(UNIT_LEFT); 
            break;
        case UNIT_RIGHT:
            host_response.command = (GET_MOTOR_RIGHT_UPPER_LIMIT | 0x80);
            limit = motor_getUpperLimit(UNIT_RIGHT); 
            break;
        default: break;
    }
    
    host_response.length = 3;
    host_response.data[0] = E_OK;
    host_response.data[1] = ((limit & 0xFF00) >> 8);
    host_response.data[2] = (limit & 0xFF);
    
    host_calcChecksum(&host_response);
    host_write(host_response);
}

static void respond_getMotorLowerLimit(uint8_t unit)
{
    uint16_t limit;
    struct host_data_packet host_response;
    
    switch (unit)
    {
        case UNIT_LEFT: 
            host_response.command = (GET_MOTOR_LEFT_LOWER_LIMIT | 0x80);
            limit = motor_getLowerLimit(UNIT_LEFT); 
            break;
        case UNIT_RIGHT:
            host_response.command = (GET_MOTOR_RIGHT_LOWER_LIMIT | 0x80);
            limit = motor_getLowerLimit(UNIT_RIGHT); 
            break;
        default: break;
    }
    
    host_response.length = 3;
    host_response.data[0] = E_OK;
    host_response.data[1] = ((limit & 0xFF00) >> 8);
    host_response.data[2] = (limit & 0xFF);
    
    host_calcChecksum(&host_response);
    host_write(host_response);
}

static void respond_getMotorNodeId(uint8_t unit)
{
    uint8_t node_id;
    struct host_data_packet host_response;
    
    switch (unit)
    {
        case UNIT_LEFT: 
            host_response.command = (GET_MOTOR_LEFT_NODE_ID | 0x80);
            node_id = motor_getNodeId(UNIT_LEFT); 
            break;
        case UNIT_RIGHT:
            host_response.command = (GET_MOTOR_RIGHT_NODE_ID | 0x80);
            node_id = motor_getNodeId(UNIT_RIGHT); 
            break;
        default: break;
    }
    
    host_response.length = 2;
    host_response.data[0] = E_OK;
    host_response.data[1] = node_id;
    
    host_calcChecksum(&host_response);
    host_write(host_response);
}

static void respond_getMotorScanId(uint8_t unit)
{
    uint8_t scan_id;
    struct host_data_packet host_response;
    
    switch (unit)
    {
        case UNIT_LEFT: 
            host_response.command = (GET_MOTOR_LEFT_SCAN_ID | 0x80);
            scan_id = motor_getScanId(UNIT_LEFT); 
            break;
        case UNIT_RIGHT:
            host_response.command = (GET_MOTOR_RIGHT_SCAN_ID | 0x80);
            scan_id = motor_getScanId(UNIT_RIGHT); 
            break;
        default: break;
    }
    
    host_response.length = 2;
    host_response.data[0] = E_OK;
    host_response.data[1] = scan_id;
    
    host_calcChecksum(&host_response);
    host_write(host_response);
}


static void respond_callWatchdogEnable()
{
    struct host_data_packet host_response;
    
    wdt_enable();
    
    host_response.command = (CALL_WATCHDOG_ENABLE | 0x80);
    host_response.length = 1;
    host_response.data[0] = E_OK;
    
    host_calcChecksum(&host_response);
    host_write(host_response);
}


static void respond_callWatchdogDisable()
{
    struct host_data_packet host_response;
    
    wdt_disable();
    
    host_response.command = (CALL_WATCHDOG_DISABLE | 0x80);
    host_response.length = 1;
    host_response.data[0] = E_OK;
    
    host_calcChecksum(&host_response);
    host_write(host_response);
}


static void respond_invalidCommand(uint8_t command)
{
    struct host_data_packet host_response;
    
    host_response.command = (command | 0x80);
    host_response.length = 1;
    host_response.data[0] = E_INVALID_COMMAND;
    
    host_calcChecksum(&host_response);
    host_write(host_response);
}
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

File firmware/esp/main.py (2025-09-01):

from machine import Pin, Timer, PWM, WDT
import as1115
import bekant


VERSION = "1.0.0"


TIMER_PERIOD_MS = 100
RESET_BUTTON_DELAY_TIME_MS = 5000
MOVING_BUTTON_DELAY_TIME_MS = 200
MEMORY_BUTTON_DELAY_TIME_MS = 500
SETTINGS_ENTER_DELAY_TIME_MS = 2000
SETTINGS_LEAVE_DELAY_TIME_MS = 4000

PIN_RESET_BUTTON = Pin(14)
PIN_BOARD_LED = Pin(27)
PIN_HMI_IRQ = Pin(32)
PIN_BUZZER = Pin(2)


class OperatingMode:     
    NONE                    = 0x00
    IDLE                    = 0x01
    STARTUP                 = 0x02
    RUNNING                 = 0x03
    SETTINGS                = 0x04
    RESTART                 = 0x05

class OperatingPhase:
    NONE                    = 0x00

class StartupPhase:
    NONE                    = 0x10
    INIT                    = 0x11
    INIT_DELAY              = 0x12
    READ_UPPER_LIMIT        = 0x13
    READ_LOWER_LIMIT        = 0x14
    WATCHDOG                = 0x15

class RunningPhase:
    NONE                    = 0x20
    WAKE_UP                 = 0x21
    READY                   = 0x22
    SLEEP                   = 0x23
    PRE_SLEEP               = 0x24

    MOVING_MANUAL           = 0x25
    MOVING_AUTOMATIC        = 0x26
    MOVING_CALIBRATION      = 0x27
    MOVING_ENDPOSITION      = 0x28

class SettingsPage:
    NONE                    = 0x30
    POSITION                = 0x31
    BRIGHTNESS              = 0x32
    ON_TIME                 = 0x33
    OFFSET                  = 0x34
    UNIT                    = 0x35
    AUDIO                   = 0x36

class Verbosity:
    SILENT                  = 0
    NORMAL                  = 1
    VERBOSE                 = 2
    DEBUG                   = 3


host_state = {
    "op_mode" : OperatingMode.NONE,
    "phase": OperatingPhase.NONE
}

default_config = {
    "desk_position_1": 200, 
    "desk_position_2": 1500,
    "desk_position_3": 4000,
    "desk_position_4": 6000,
    "desk_offset": 0,
    "display_unit": "cm",
    "display_brightness": 4,
    "display_on_time": 10,
    "audio": True
}


def debug(v_level, message):
    if (VERBOSITY_LEVEL >= v_level):
        print(message)


def cb_hmi(pin):
    if (host_state["phase"] == RunningPhase.SLEEP):
        host_state["phase"] = RunningPhase.WAKE_UP


def cb_timer(timer):
    global timer_lapsed
    timer_lapsed = True


def save_config(data, filename="config.json"):
    import ujson
    with open(filename, "w") as f:
        ujson.dump(data, f)


def load_config(filename="config.json"):
    import ujson
    try:
        with open(filename, "r") as f:
            pass

    except OSError:
        debug(Verbosity.VERBOSE, "Config file does not exist. Creating a default config...")
        with open(filename, "w") as f:
            ujson.dump(default_config, f)
    
    finally:
        with open(filename, "r") as f:
            return ujson.load(f)


def write_memory_position(memory_button:int, desk_position:int):
    if (memory_button == hmi.Keys.BUTTON_1):
        config["desk_position_1"] = desk_position
    elif (memory_button == hmi.Keys.BUTTON_2):
        config["desk_position_2"] = desk_position
    elif (memory_button == hmi.Keys.BUTTON_3):
        config["desk_position_3"] = desk_position
    elif (memory_button == hmi.Keys.BUTTON_4):
        config["desk_position_4"] = desk_position
    else:
        pass


def timer_start(period_ms: int):
    global hmi_timer 
    debug(Verbosity.DEBUG, "Runtime timer started.")
    hmi_timer.init(period=period_ms, mode=Timer.ONE_SHOT, callback=cb_timer)


def timer_stop():
    global hmi_timer
    debug(Verbosity.DEBUG, "Runtime timer stopped.")
    hmi_timer.deinit()


def buzzer_start():
    global buzzer
    debug(Verbosity.DEBUG, "Buzzer started.")
    buzzer = PWM(PIN_BUZZER, freq=4000, duty_u16=32768)


def buzzer_stop():
    global buzzer 
    if (buzzer != None):
        debug(Verbosity.DEBUG, "Buzzer stopped.")
        buzzer.deinit()


def led_enable(enable:bool):
    global board_led
    if (enable == True):
        board_led.value(0)
    else:
        board_led.value(1)


def display_brightness(brightness:int):
    if (brightness == 1):
        hmi.set_brightness(1)
    elif (brightness == 2):
        hmi.set_brightness(4)
    elif (brightness == 3):
        hmi.set_brightness(8)
    elif (brightness == 4):
        hmi.set_brightness(15)
    else:
        pass
        

def display_update():
    global desk_position 
    global prev_height
    global prev_phase
    height = 0

    if (host_state["op_mode"] == OperatingMode.RUNNING):

        if (host_state["phase"] in {RunningPhase.PRE_SLEEP, RunningPhase.SLEEP}):
            if (prev_phase != host_state["phase"]):
                hmi.clear()
       
        elif (host_state["phase"] == RunningPhase.READY):
            if (config["display_unit"] == "cm"):
                height = bekant.position_to_height(desk_position, offset=config["desk_offset"], unit="cm") 
                if ((height != prev_height) or (prev_phase != host_state["phase"])):
                    hmi.show_number(height)
                    prev_height = height
            elif (config["display_unit"] == "inch"):
                height = bekant.position_to_height(desk_position, offset=config["desk_offset"], unit="inch") 
                if ((height != prev_height) or (prev_phase != host_state["phase"])):
                    hmi.show_number(height, dp=True)
                    prev_height = height
       
        elif (host_state["phase"] in {RunningPhase.MOVING_MANUAL, RunningPhase.MOVING_AUTOMATIC}):
            if (config["display_unit"] == "cm"):
                height = bekant.position_to_height(desk_position, offset=config["desk_offset"], unit="cm") 
                hmi.show_number(height)
            elif (config["display_unit"] == "inch"):
                height = bekant.position_to_height(desk_position, offset=config["desk_offset"], unit="inch") 
                hmi.show_number(height, dp=True)

        elif (host_state["phase"] == RunningPhase.MOVING_CALIBRATION) and (prev_phase != RunningPhase.MOVING_CALIBRATION):
            display_text = str("C AL")
            hmi.show_text(display_text)
        
        elif (host_state["phase"] == RunningPhase.MOVING_ENDPOSITION) and (prev_phase != RunningPhase.MOVING_ENDPOSITION):
            display_text = str("E nd")
            hmi.show_text(display_text)


    elif (host_state["op_mode"] == OperatingMode.SETTINGS):

        if (host_state["phase"] == SettingsPage.POSITION) and (prev_phase != SettingsPage.POSITION):
            hmi.show_text("P: _")
       
        elif (host_state["phase"] == SettingsPage.BRIGHTNESS) and (prev_phase != SettingsPage.BRIGHTNESS):
            display_text = str("L: ")
            display_text += str(config["display_brightness"])
            hmi.show_text(display_text)
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

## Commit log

2025-08-21 initial commit
    KiCad project containing all pcb files (schematic and board) plus 3d models, gerber files, datasheets, images, etc.
2025-08-21 Add files via upload
    KiCad project with all pcb files (schematic and board) plus 3d models, gerber files, datasheets, images, etc.
